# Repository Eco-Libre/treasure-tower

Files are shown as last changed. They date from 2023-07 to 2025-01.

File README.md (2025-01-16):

# Eco-Libre Treasure Tower

The Eco-Libre Treasure Tower is a zero-waste recycling station with humanure dry composting toilets, urine collection, hand washing stations, and storage for anaerobic decomposition of human waste.

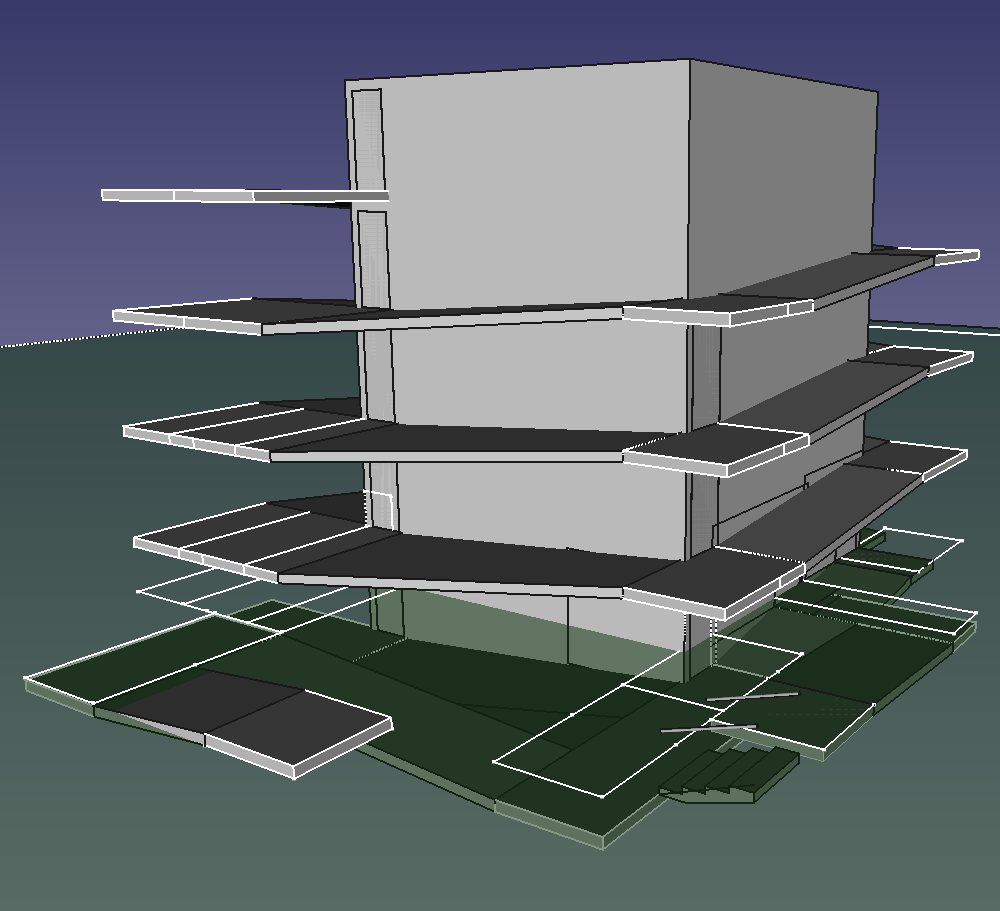
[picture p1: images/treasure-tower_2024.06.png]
Screenshot of CAD file
</a>

This facility is 6-stories high and features one toilet on each floor. Each toilet and floor is barrier-free with a ramp that winds around-and-up the 6-meter by 7-meter structure.

## Features

1. 6x Dry Composting Toilets
1. Urine Collection
1. Rain water collection
1. Hand washing station
1. Anarobic Storage of 200L drums
1. Storage of other recyclable materials
1. Clear roofing panels
1. Light well in center
1. Floors drains to septic system for safe cleanup

# License

Copyright (C) 2023 Michael Altfield and the Eco-Libre Team

The contents of this repo are under the GPL version 3 or later.
In addition, any content other than code can also be used, at your
choice, under CC-BY-SA version 4.0.

This program is free software: you can redistribute it and/or modify
it under the terms of the GNU General Public License as published by
the Free Software Foundation, either version 3 of the License, or
(at your option) any later version.

This program is distributed in the hope that it will be useful,
but WITHOUT ANY WARRANTY; without even the implied warranty of
MERCHANTABILITY or FITNESS FOR A PARTICULAR PURPOSE.  See the
GNU General Public License for more details.

You should have received a copy of the GNU General Public License
along with this program.  If not, see <http://www.gnu.org/licenses/>.

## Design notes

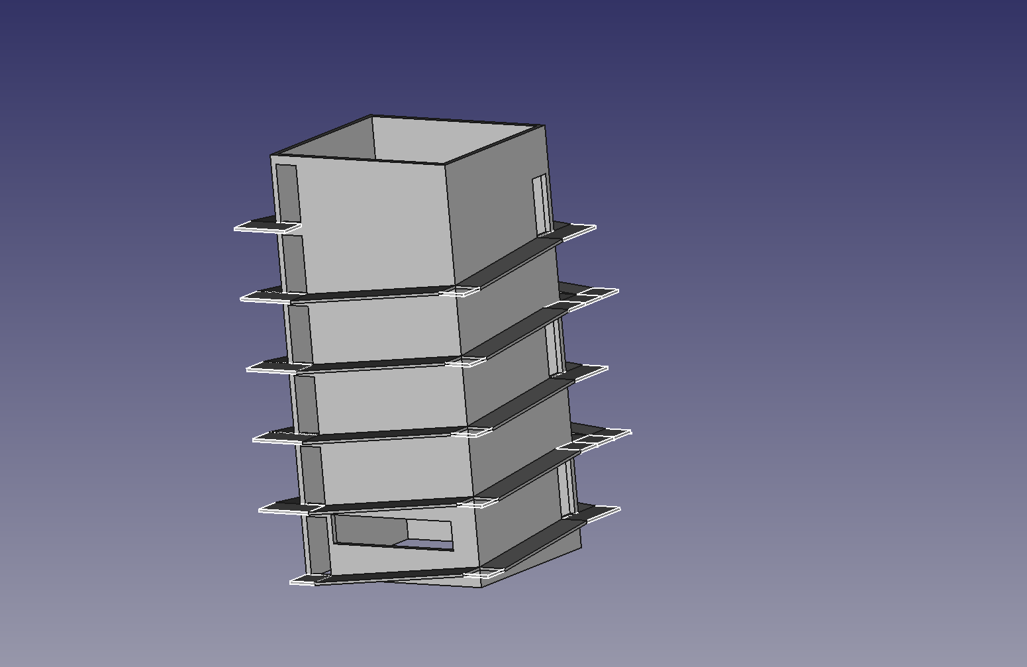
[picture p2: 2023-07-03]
images/treasure-tower_2023.07.png

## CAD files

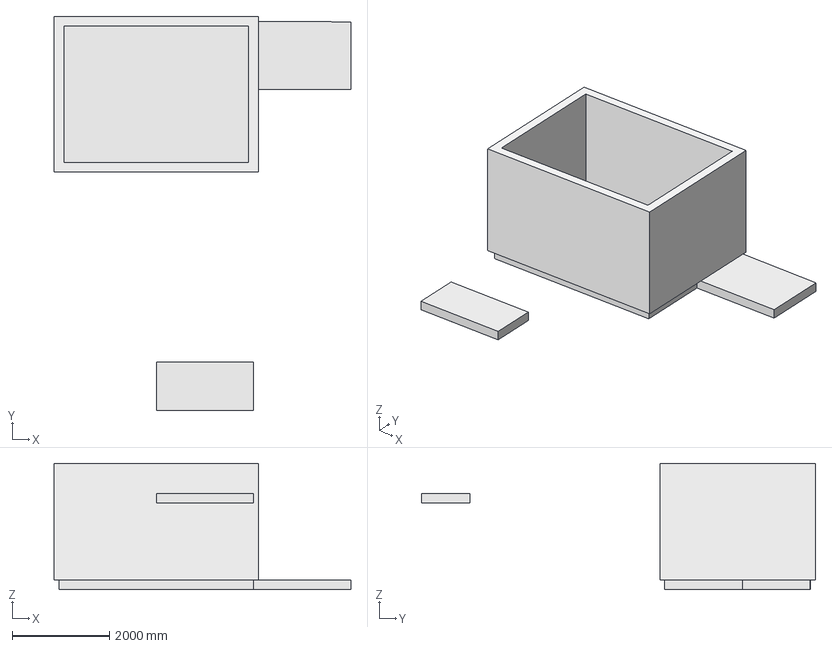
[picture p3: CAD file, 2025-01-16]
treasure-tower.FCStd
6100.0 x 8100.0 x 2600.0 mm
wall_changing_place2
wire_changing_place2_floor
extrude_changing_place2_floor
extrude_wc1b

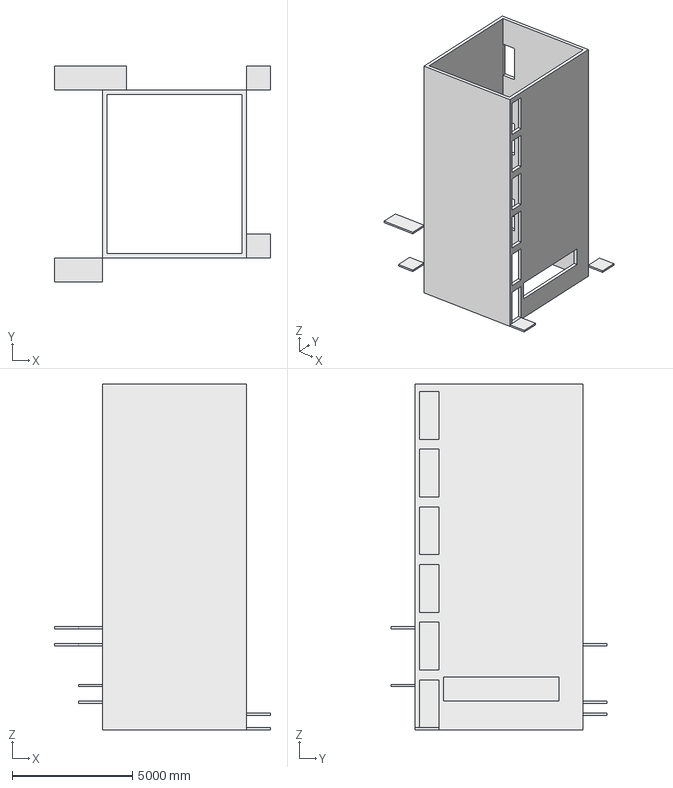
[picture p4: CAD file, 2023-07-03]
treasure-tower_2024.06.FCStd
9000.0 x 9000.0 x 14400.0 mm
Wall
N deposit closet landing 1
NE landing
SW landing
N deposit closet landing (bypass)
SW landing (w bypass)
entrance 1

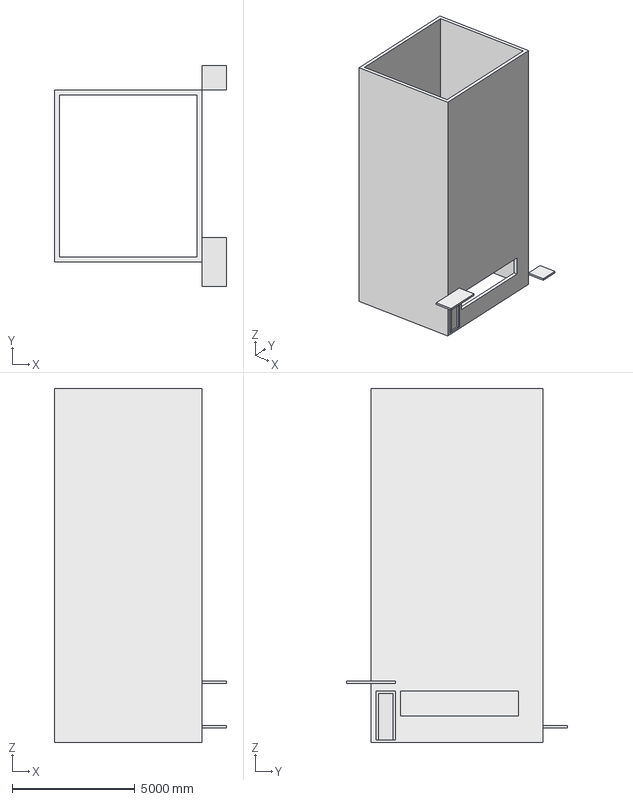
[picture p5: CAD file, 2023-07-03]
treasure-tower_2023.07.FCStd
7000.0 x 9000.0 x 14400.0 mm
entrance landing
NE landing
exterior walls
main entry door
deposit closet door

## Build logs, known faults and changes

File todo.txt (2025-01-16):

TODO

 * add stairs down to the first WC
 * add compost unloading platform outside the second-floor maintenance door (the first door above ground level that's ~1m above the ground level) that pours into a hopper for collection in a wheelbarrow or tractor trailer at ground-level
 * add sinks
 * add half-basement (?) so first deposit closet is ground-level
 * add roof
 * add doors
 * add windows (except sheer walls)
 * figure out the thickness of the walls, which affects the footprint of the buildings and wall-to-wall clearance of all the rooms
  - after setting wall thickness, confirm that the wall-to-wall clearance of every room meets our requirements
 * add WCs on second and third floor. Don't add one to the 5th floor (there's no vertical) and also don't add one to the 4th floor (this gives us additional capacity for storing the pallets as they compost; I calculate it increases from 78 pallets to 108 pallets [double-stacked where possible], which is enough for 30 people [filling one pallet every 7 days] and 2 years of compost time [double most recommendations])
 * make the ramps 1.5 meters wide and all the landings 1.8 meters wide (turning space), to accommodate wheelchair users https://www.iwa.ie/access-guidelines/great-outdoors-access-guidelines/7-access-to-the-built-environment/
    - also check turning radius needed for a hydraulic hand-truck pulling a standard Euro pallet (1.2 meters long, 0.8 meters wide, 1 meter tall) https://engineering.stackexchange.com/questions/60826/warehouse-aisles-and-ramp-requirements-for-pallet-hand-trucks

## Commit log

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2023-07-02 added one window. Unfortunately it appears that making an array of windows doesn't really work as some of the elements don't copy. for example, you can't "see-through" the array'd copies of the windo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
    * https://forum.freecad.org/viewtopic.php?t=16075
    [treasure-tower.FCStd]
2023-07-02 Apparently a "clone" doesn't copy the attributes either. Only a copy & paste does, and that requires you to uncheck everything else in the tree list other than just the window
    [treasure-tower.FCStd]
2023-07-02 removed array of windows and also hiding the window object itself leaves a hole for both the window and the door, which I prefer at this stage
    [treasure-tower.FCStd]
2023-07-02 moved deposit closet door to the left-side of the platform (leaves space for the tie column
    [treasure-tower.FCStd]
2023-07-02 attempting to rebuild with the deposit closets staggered
    Unfortunately I realized that there would only have been space for a 1.4 meter door and usable space in the deposit closet if they're stacked ontop of each other (because 1 meter of the 2.4 meter flo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
    Rather than make some users feel claustrophobic, it make sense to stagger the deposit closets so they have a full 2.4 meters of space.
    To do this without fucking-up the rise/run on the ramp, we'll need the ramp to fork -- one path will continue level to the next deposit closet and the other path will go outward and continue sloping 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
    [treasure-tower_2023.07.FCStd]
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2023-07-02 better landing progress. fixed height of entrance
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2023-07-02 fixed the count of landings
2023-07-02 Fail to create ramp to bypass
    I tried to create a wire ramp between the N deposit closet that bypasses the level path to the W deposit closet, but I couldn't find a way to snap at 1-meter intervals
    TODO: draw the wire ramps to and around the W deposit closet.
    You may need to re-sketch/extrude the N deposit closet landing such that it's three distinct 1-sq-meter squares instead of one long 1mx3m square, so that you can snap to the right points
2023-07-03 added first window. also realized some height issues.
    While I think this design masterfully handles the slope of the walkways and the spacing of deposit closets at an offset higher than the main entrance (so they're elevated above the 200L drum that they're "depositing" into, they might actually be too high.
    I chose 1.2 meters because that's where the seismic band should be placed in confined masonry.
    But that means that's just where the user's feet will be. In a squat toilet, that means they're hovering 1.2 meters above the ground. The standard 200L drum is "just under 880 mm tall"
    * https://en.wikipedia.org/wiki/Drum_(container)
    That means a squat toilet would be 1200-880 = 0.4 meters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
2024-06-08 changed the footprint to 8 meters x 8 meters
    I'm changing the size to be 8 meters x 8 meters. That allows for a 2 x 2 meter space in the center for an elevator (1x1 isn't big enough for 1.2m pallets plus buffer for the elevator structure itself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
    This is huge, but I think it's best if we want it to be accessible and easy to move pallet-sized boxes full of shit between floors.
    [treasure-tower.FCStd, treasure-tower_2024.06.FCStd]
2024-06-08 added ground and basement
    I drew a ground 100 meters x 100 meters wide, colored it "green", set it to 50% transparent, and then I dropped the structure down 1.2 meters.
    This means that the doors to enter the Changing Places (plus maybe 3 more able-bodied WCs) will be at ground level. They will deposit into containers that are located in the basement below. When they're filled, someone can use a standard hand truck for pallets to move the ~1.2 meter long x 0.8 meter wide x 1 meter high container full of shit up to another floor for storage (aerobic composting takes >= ~1 year) and then replace it with an empty one
    [treasure-tower.FCStd]
2024-06-08 reduced structure height to 5 floors
    after reading Mexican, Colombian, and EU building codes for confined masonry structures, it became clear that 5 stories is the max. There are some others, eg India, that allow 6-stories -- but probab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
    According to the Eurocode, these "storey" restrictions do not restrict below-ground floors (eg basements), so 5 storeys above ground + 1 storey below ground should be OK.
    * page 203 https://www.confinedmasonry.org/wp-content/uploads/2009/09/Eurocode-8-1-Earthquake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
    [treasure-tower.FCStd]
2024-06-08 created a new "wall" because the old one didn't appear to be located at 0,0
    [treasure-tower.FCStd]
2024-06-08 added our first entrance door
    this door is located at 0,0. next I'll adjust it based on the values in the spreadsheet, and see if I can make an array of it
    [treasure-tower.FCStd]
2024-06-08 adjusted location of first maintenance door
    Rather than calling it an "entrance door", I'm remaining it to "maintenance door" -- because this is the door that people will enter to do maintenance (as opposed to the doors that people will enter 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
    I set the wall thickness to be 200 mm in the spreadsheet and moved the door over this distance in the X direction. Then sunk the door -1 * the basement depth, so it becomes our first "maintenance doo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
    [treasure-tower.FCStd]
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2024-06-08 added platform for the maintenance door 0
    In this commit, I created a sketch (which references the lines of the main floor sketch) and adds a flat "platform" that goes at the base of the maintenance door 0. I made the "width" of the platform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
    I also added the extruded "part" of the platform, to make it 3D. Currently it's extruded to 200 mm, but this is also defined in the spreadsheet (as ramp_thickness)
    Next, I'll create an array of these ramps. Then I'll create platforms for the other two doors.
    Per my notes in todo.txt, I'll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
    [treasure-tower.FCStd]
2024-06-08 added an array of platforms for the entrance to the maintenance door
    Next I need to figure out where the platforms will go for the two WCs on the next wind of the ramp.
    Since we changed to 8 meters x 8 meters for the external wall footprint of the structure, it gets us closer to meeting the US ADA slope.
    US ADA ramp slope is 1" of rise for every 12" of run. We're not using inches, but the ratio still applies. 1/12 = 0.083.
    Australia is less strict. They have 1/8 = 0.125.
    Previously I was targeting somewhere between these -- where rise/run = 0.083 - 0.125. From my notes, we chose the 6x7 meter structure specifically so we could meet that requirement. We had 5+5+6+6-1 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
    [treasure-tower.FCStd]
2024-06-08 I made the platform for the first WC. The floor of the first WC appears to be 0.57229 meters above the floor of the basement. To fit a 1-meter-high crate under it, that means the toilet needs to sit 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
    A 40 cm toilet is a bit low, but I think it would work for people of all sizes. A 60 cm toilet would work too, but it probably wouldn't work for people of all sizes (at least, not with their feet on 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
    [treasure-tower.FCStd]
2024-06-08 added platform for wc #2
    this one is just over 1 meter off the floor of the basement, which is perfect for a squat toilet.
    [treasure-tower.FCStd]
2024-06-08 added sketches for ramp corners
    this commit adds sketches for the flat landing on the last two corners of the wrap-around ramp
    [treasure-tower.FCStd]
2024-06-08 added extrusions for ramp corners
    the final corner that connects to the maintenance door on floor #2 appears to be perfectly level with the platform for the maintenance door #2, so it appears that our calculations using the slope of 2.4/29 = 0.082758621 to determine the z-index placement for each of these ramp platforms was correct.
    And that means we've achieved a slope within the spec of the US ADA. Hooray!
    [treasure-tower.FCStd]
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2024-06-08 cleanup 6x7 -> 8x8 structure
    this commit deleted all the elements left-over from the 6 meter x 7 meter structure (which we've now replaced with an 8 meter x 8 meter structure)
    [treasure-tower.FCStd]
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2024-06-08 added door for changing place
    my goal is to have two changing places WCs on the ground floor. this is a bit tricky because:
    1. CP toilets should be 4 meters x 3 meters
    2. CP toilets should have min door clearance of 1 meter width
    3. the wrap-around ramp is kinda in the way of possible doors on the ground floor, limiting the possible height of these doors (which, well, we can probably get away with being shorter than the standard 1986 mm -- since CP users are likely in wheelchairs)
    I'm certain that I can add a door for one CP toilet. The other door has two problems:
    1. The path to the door itself would block the path of the ramp that goes from the ground-level down to the 0th maintenance d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
    [treasure-tower.FCStd]
2024-06-08 removed the ramp from the gound-level
    in this commit, I've removed one section of the ramp as it cuts across the ground level, where it would block the entrance doors to the WCs on ground level (see last commit for more info)
    one side that was removed will be replaced by another ramp that makes a 180 degree turn (instead of a 90 degree turn in the other direction) and the other side already hits ground level after 1 meter, so no extension there is needed
    [treasure-tower.FCStd]
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2024-06-08 finished ramp to basement
    This commit finishes the ramp to basement, such that it turns 180 degrees so as not to intersect with the entrance to our WCs on the ground level.
    Unfortunately, I just went from the first turn to the ground level, without calculating the slope. The result is that the slope is 0.117 -- which does satisfy Australia's requirements, but falls short of meeting the US requirements. For reference, our slop for the rest of the ramp around the structure is 0.082758621.
    We could probably get away with keeping it as-is, because wheelchair users shouldn't need to go into the maintenance area of the basement. But we will be hauling a lot of extremely heavy hand truck loads of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
    [treasure-tower.FCStd]
2024-06-08 added doors for all three WCs on the ground floor
    This commit places the doors for the entrance to the WCs on the ground floor.
    In reality, only one of the doors is actually at "ground level". I decided to make the second Changing Place WC 200 mm below ground level, so that the door would be a proper 1985 mm high. Note that both of these CP doors are 1.2 meters wide. That's because the min clearance for CP doors is 1 meter, and the additional 200 mm gives us 100 mm on either side for the door framing. We probably won't need that much, but it's not an issue to have a bit more than 1 meters clearance for wheelchairs entering the CP WC
    The third WC is ~0.620 meters below ground level. It's no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
    [treasure-tower.FCStd]
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2024-06-08 fixed slight offset of one of the CP WCs
    [treasure-tower.FCStd]
2024-06-08 added ramp between the two CP platforms
    This commit adds a ramp between the two Changing Places WCs. The first one is 200 mm below ground-level, and the second one is at ground-level.
    The distance between the two platforms is 1.6 meters. It changes 0.2 meters, so that's rise/run = 0.2/1.6 = 0.125, which too steep to meet US ADA standards, but it does Australia's maximum slope for wheelchair ramps. It's not ideal, but I can't really change the placement of the door due to other constraints. It doesn't matter too much, though because we're going to add a proper ramp perpendicualr to this one that goes down to the first CP WC. This ramp was just additional. I figure it would be nice for some f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
    [treasure-tower.FCStd]
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2024-06-08 added steep ramp from wc1 to cp1
    this commit added a very steep ramp that connects the first able-bodied wc to the Changing Places WC. Again, this isn't to be used by wheelchairs; it's a superfluous shortcut for those who are able-bodied.
    [treasure-tower.FCStd]
2024-06-08 fixed basement ramp
    I fixed the basement ramp to be the actual slope we need. That put a platform that's 241.38 mm below the surface of the ground. At our existing slope, we just need another ~ 2.92 meters of ramp to reach the surface on the next bend
    [treasure-tower.FCStd]
2024-06-08 finished basement ramp
    this commit finishes the whole ramp down to the basement, such that its slope is either flat (at turn-arounds) or 0.082758621. Meeting this slope, the last little section ended up being very short -- only 2.916674989 meters long.
    [treasure-tower.FCStd]
2024-06-09 added floor slabs and light well
    I realized last night that the first changing place cuts into our light well.
    This commit adds the floor slabs for the maintenance floors and the light well, which we'll pocket out of those slabs. That should help us "see" issues like this in the future.
    Next I need to actually pocket out the towering light well solid out of the floor slabs. Then I need to change the size of the first Changing Places WC from 3x4 to 4x3. That means we only have 1 meter width (but plenty of length) for the last WC. It'll be tight, but it should work.
    [treasure-tower.FCStd]
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2024-06-09 changed ramp width from 1 meter to 2 meters
    I spent most the day today trying to figure out if the ramps that we have would be sufficient to use for moving 1200 mm x 800 mm EUR-pallets (~1 meter high, full of composting shit) on manual hydraulic pallet jacks between floors.
    My conclusion was that the slope that we have wouldn't be a problem. Currently we have a slope of 2.4/29 = 0.082758621 slope (8.28% grade). That's just slightly better than the minimum ADA requirement of 1/12 = 0.083333333 slope (8.33% grade). Unfortunately, all the EU standards are locked-up in PDFs that you have to pay for (wtf), but it appears that 1:20 is not uncommon. That made me a bit scared, but 1:12 should be s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
    [treasure-tower.FCStd]
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2024-06-10 fixed ramp 1 to be a "wedge" between landings
    this commit changes the ramp 1 to expand out to the new landing size at the maintenance doors. It doesn't quite meet the turning radius of 2 meters, but it comes close enough (to this already conservative number) that I think it's good enough.
    [treasure-tower.FCStd]
2024-06-10 fixed remaining ramps
    this commit finishes the change of the ramp from 1-meter width to 2-meter widths
    [treasure-tower.FCStd]
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2024-06-11 fixed ramp to cp1
    This commit fixes the ramp to changing place 1. Since this is the one ramp that we definitely expect to be used by wheelchair users (and because the dimensions allow for it), I made it have a slope of 1:20 (instead of ~1:12). This means that, for a rise of 200 mm, we need (0.2 meter rise) / (1/20) = 4 meters of run
    [treasure-tower.FCStd]
2024-06-11 added stairs to WC1
    In this commit, I added a (superfluous) set of stairs descending down to the WC1 (and the basement). This allows faster access to what is probably going to be the most-commonly-used toilet for folks who can take stairs.
    While the wheelchair ramp follows the best-practice of 1:20 (5% grade), the stairs follows the best-practice of rise of 150 mm & going of 300 mm = 150/300 = 50% grade. The stairs didn't line-up exactly as I expected, so I'm not 100% on my math here. The WC1 is located 820.69 mm below the surface of the ground (it's a strange number that's a result of the slop of the ramp, which is the length of all sides of the building minus 3 meters for the landing), an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
    [treasure-tower.FCStd]
2024-06-12 finished ramp to basement
    this commit finishes the corrections for the ramp down to the basement, since we modified the maintenance door platform to be 3.5 meters long and the ramp itself to be 2 meters wide.
    [treasure-tower.FCStd]
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2024-06-13 lowered entire structure 200 mm more
    This commit lowered the walls and basement slab an additional 0.2 meters, which is the current setting for the thickness of the floor slabs.
    This was necessary because the wc1 floor slab was only 200 mm above the basement slab. With a toilet seat height of 480 mm, we'd need at lest 520 mm of clearance between the top of the basement floor slab and the bottom of the wc1 floor slab in-order to fit the 1000 mm pallet bin underneath the toilet seat.
    I got 200 mm additional by lowering the basement floor slab.
    I got 200 mm additional by raising the wc1 floor slab. Now there's a 200mm step-up for these WCs. Not ideal, but also not an issue as we have two Cha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
    [treasure-tower.FCStd]
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
